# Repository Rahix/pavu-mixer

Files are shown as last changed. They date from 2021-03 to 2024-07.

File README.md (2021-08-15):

 Pavu Mixer
=================================
_Pavu Mixer_ is a hardware mixing desk for controlling
[PulseAudio](https://www.freedesktop.org/wiki/Software/PulseAudio/) streams on
a connected computer.  Think of it as a hardware version of
[`pavucontrol`](https://freedesktop.org/software/pulseaudio/pavucontrol/).

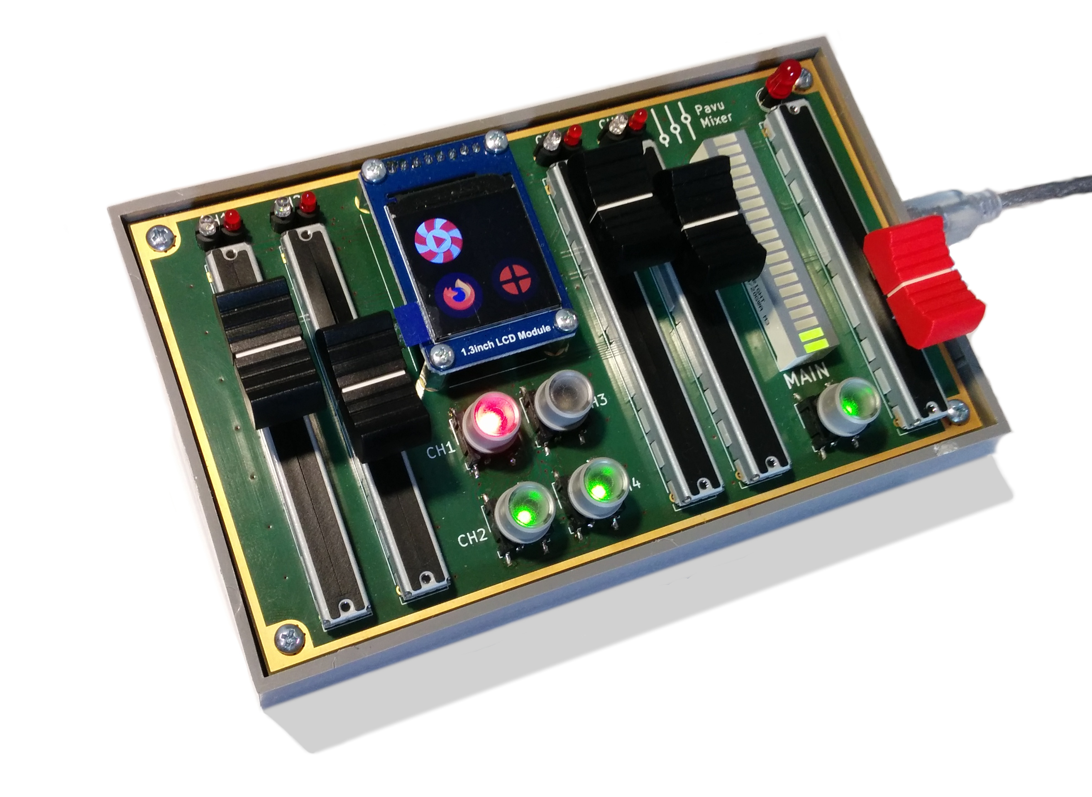
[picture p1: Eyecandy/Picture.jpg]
Pavu Mixer in Action


More pictures in [`Eyecandy/`](./Eyecandy).

### Hardware
The _Pavu Mixer_ is currently just a PCB fitted as the front plate of a
[console enclosure][enclosure].  This remedies the need for a custom front
plate.  Beneath it, an [STM32F3DISCOVERY][discovery] eval board is used as the
controller.  Connection to the computer is done over USB.

Following are the capabilities of the current hardware:

- 4 "Application Channels" + 1 "Main" Channel
- [240x240 LCD Display][display-board] (driver available in
  [`waveshare-display/`](./waveshare-display) subdirectory)
- Per channel:
  - Mono Volume Fader
  - Mute Button with green/red indicator LED
  - LED as brightness-based level indicator
  - Red LED as status indicator
- For the main channel, the level indicator is a 20 segment LED-bargraph
  instead.
- USB-B socket for connection to the computer

[enclosure]: https://www.tekoenclosures.com/en/products/family/PU/series/pult-36
[discovery]: https://www.st.com/en/evaluation-tools/stm32f3discovery.html
[display-board]: https://www.waveshare.com/wiki/1.3inch_LCD_Module

### Firmware/Software
The firmware on the [STM32F3DISCOVERY][discovery] board exposes all of the "UI"
(faders, buttons, indicators, display) to the host via a custom USB class.
Messages are serialized using [`postcard`](https://crates.io/crates/postcard).

On the host, a daemon is running which communicates to the hardware and keeps
track of PulseAudio state.  It has a configuration file for selecting which
channel controls which applications.  Streams are then attached to the mixer
channels automatically when they appear.

The firmware and host-side software are still in development - these features
are subject to change.

- New application streams are attached to channels based on a configurable
  property-matching table.  All streams connected to a channel will be forced
  to the volume reported by the fader.
- Main channel controls the currently selected default sink.
- Whenever a channel has an active stream, its reported icon will be displayed
  on the LCD.  For streams which do not properly report an icon, a second
  matching table can be used to select custom icons.

### Alternative Hardware
Right now, only the _Pavu Mixer_ hardware is supported.  As this board is not
commercially available, but a hardware mixer for PulseAudio could be
interesting for other people as well, I am open to extend the host-daemon to
support other boards as well.  For example, there are a lot of MIDI-based
digital audio mixers which would be a good candidate for support.  Please open
an issue on GitHub or contact me directly if interested.

## Project Structure
| Path | Contents |
| -- | -- |
| `Eyecandy/` | Pictures and "rendered" schematic ([`Pavu-Mixer-Schematic.pdf`](Eyecandy/Pavu-Mixer-Schematic.pdf)). |
| `Hardware/` | KiCAD project for the interface board & other hardware related files. |
| `hardware-tests/` | Test-firmware for demonstrating functionality of all parts of the hardware. |
| `common/` | Definitions shared between firmware and host-software (for [`postcard`](https://crates.io/crates/postcard) serdes). |
| `firmware/` | Firmware for the [STM32F3DISCOVERY][discovery] board. |
| `host-daemon/` | Host-side daemon for mixer communication and PulseAudio interaction. |
| `waveshare-display/` | Driver for the LCD screen (see its [README](waveshare-display/README.md) for details). |

## License
It is a difficult story... Individual parts of this project are licensed under
different terms:

- All files in the `Hardware/` directory (exception below) are licensed under
  the [CERN-OHL-W](LICENSE-HARDWARE).
- Files in `Hardware/3D` are licensed under [MIT](Hardware/3D/LICENSE-3D).
- The display driver in `waveshare-display/` is dual licensed under Apache 2/MIT
  as detailed in its own [README](waveshare-display/README.md).
- The remaining files of this project (including `common/`, `firmware/`,
  `hardware-tests/`, and `host-daemon/`) are licensed under the
  [GPL v3](LICENSE-SOFTWARE).

## Contribution
Unless you explicitly state otherwise, any contribution intentionally submitted
for inclusion in the work by you, as defined in the Apache-2.0 license, shall
be licensed as above, without any additional terms or conditions.

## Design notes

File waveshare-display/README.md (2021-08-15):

Driver for the "1.3inch LCD Module" from Waveshare
--------------------------------------------------
Driver for Waveshare's "[1.3inch LCD Module](https://www.waveshare.com/wiki/1.3inch_LCD_Module)" (240x240, RGB565):

1.3inch LCD Module

The module uses an ST7789 display controller. The driver code is adjusted for
the specific LCD panel.  I documented the initialization procedure in
[Initialization.md](Initialization.md).

The driver is intentionally barebones and only contains what is needed for
_Pavu Mixer_.  It might make sense to add proper interoperability with
[`embedded-graphics`](https://crates.io/crates/embedded-graphics) at some
point... I'll gladly accept contributions :)

## License
This display driver is licensed under either of

 * Apache License, Version 2.0 ([LICENSE-APACHE](LICENSE-APACHE) or <http://www.apache.org/licenses/LICENSE-2.0>)
 * MIT license ([LICENSE-MIT](LICENSE-MIT) or <http://opensource.org/licenses/MIT>)

at your option.

## Contribution
Unless you explicitly state otherwise, any contribution intentionally submitted
for inclusion in the work by you, as defined in the Apache-2.0 license, shall
be dual licensed as above, without any additional terms or conditions.

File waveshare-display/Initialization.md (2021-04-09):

Initialization Sequence
=======================
This is a documentation of the initialization sequence found in the official
example code.

#### `0x36` - `MADCTL`: Memory Data Access Control
Values: `0x00`

Bits:
- `7`: `MY` - Page Address Order
  - 0: Top to Bottom (**selected**)
  - 1: Bottom to Top
- `6`: `MX` - Column Address Order
  - 0: Left to Right (**selected**)
  - 1: Right to Left
- `5`: `MV` - Page/Column Order
  - 0: Normal (**selected**)
  - 1: Reverse Mode
- `4`: `ML` - Line Address Order
  - 0: LCD Refresh Top to Bottom (selected)
  - 1: LCD Refresh Bottom to Top
- `3`: `RGB` - BRGB/BGR Order
  - 0: RGB
  - 1: BGR
- `2`: `MH` - Display Data Latch Order
  - 0: LCD Refresh Left to Right
  - 1: LCD Refresh Right to Left

#### `0x3A` - `COLMOD`: Interface Pixel Format
Values: `0x05`

Bits:
- `6:4`: RGB interface color format
  - `101`: 65K of RGB interface
  - `110`: 262K of RGB interface
  - `0`: Undocumented value which is used here?
- `2:0`: Control interface color format
  - `011`: 12bit/pixel
  - `101`: 16bit/pixel (**selected**)
  - `110`: 18bit/pixel
  - `111`: 16M truncated

The "RGB interface color format" isn't set here; the datasheet suggests using
`0x55` for our purposes... Need to check what is going on here.

#### `0xB2` - `PORCTRL`: Porch Setting
Values: `0x0C 0x0C 0x00 0x33 0x33`

Probably empirically gained values for the porch settings, let's keep them.
"Separate porch control" is disabled.

#### `0xB7` - `GCTRL`: Gate Control
Values: `0x35`

Bits:
- `6:4`: VGH Setting (Voltage)
  - 0: 12.2 V
  - 1: 12.54 V
  - 2: 12.89 V
  - 3: 13.26 V
  - 4: 13.65 V
  - 5: 14.06 V
  - 6: 14.5 V
  - 7: 14.97 V
- `2:0`: VGL Setting (Voltage)
  - 0: -7.16 V
  - 1: -7.67 V
  - 2: -8.23 V
  - 3: -8.87 V
  - 4: -9.6 V
  - 5: -10.43 V
  - 6: -11.38 V
  - 7: -12.5 V

#### `0xBB` - `VCOMS`: VCOM Setting
Values: `0x19`

`0x19` -> 0.725 V

#### `0xC0` - `LCMCTRL`: LCM Control
Values: `0x2C`

Bits:
- `6`: XMY: XOR MY setting in command 36h
- `5`: XBGR: XOR RGB setting in command 36h (**selected**)
- `4`: XREV: XOR inverse setting in command 21h
- `3`: XMH: this bit can reverse source output order and only support for RGB
  interface without RAM mode (**selected**)
- `2`: XMV: XOR MV setting in command 36h (**selected**)
- `1`: XMX: XOR MX setting in command 36h
- `0`: XGS: XOR GS setting in command E4h

#### `0xC2` - `VDVVRHEN`: VDV and VRH Command Enable
Values: `0x01`

- `0`: VDV and VRH register value comes from NVM.
- `1`: VDV and VRH register value comes from command write (**selected**).

#### `0xC3` - `VRHS`: VRH Set
Values: `0x12`

`0x12` -> VAP: 4.45+( vcom+vcom offset+vdv)
`0x12` -> VAN: -4.45+( vcom+vcom offset-vdv)

#### `0xC4` - `VDVS`: VDV Set
Values: `0x20`

`0x20` -> VDV: 0 V

#### `0xC6` - `FRCTRL2`: Frame Rate Control in Normal Mode
Values: `0x0F`

Bits:
- `4:0`: RTNA
  - `0x0F` -> 60 Hz
- `7:5`: NLA - Inversion selection in normal mode
  - `0x0`: dot inversion (**selected**).
  - `0x7`: column inversion.

#### `0xD0` - `PWCTRL1`: Power Control 1
Values: `0xA4 0xA1`

`0xA4` is a fixed parameter?

Second Parameter Bits:
- `7:6`: AVDD, `2` -> 6.8 V
- `5:4`: AVCL, `2` -> -4.8 V
- `1:0`: VDS, `1` -> 2.3 V

#### `0xE0` - `PVGAMCTRL`: Positive Voltage Gamma Control
Values: `0xD0 0x04 0x0D 0x11 0x13 0x2B 0x3F 0x54 0x4C 0x18 0x0D 0x0B 0x1F 0x23`

Gamma Curve, probably calibrated for this device...

#### `0xE1` - `NVGAMCTRL`: Negative Voltage Gamma Control
Values: `0xD0 0x04 0x0C 0x11 0x13 0x2C 0x3F 0x44 0x51 0x2F 0x1F 0x1F 0x20 0x23`

Gamma Curve, probably calibrated for this device...

#### `0x21` - `INVON`: Display Inversion On
Self-explaining...

#### `0x11` - `SLPOUT`: Sleep Out
Self-explaining...

Interestingly, other drivers have added a delay after sending `SLPOUT` but here
this is not the case.  Maybe the timing allows for this here?

#### `0x29` - `DISPON`: Display On
Self-explaining...

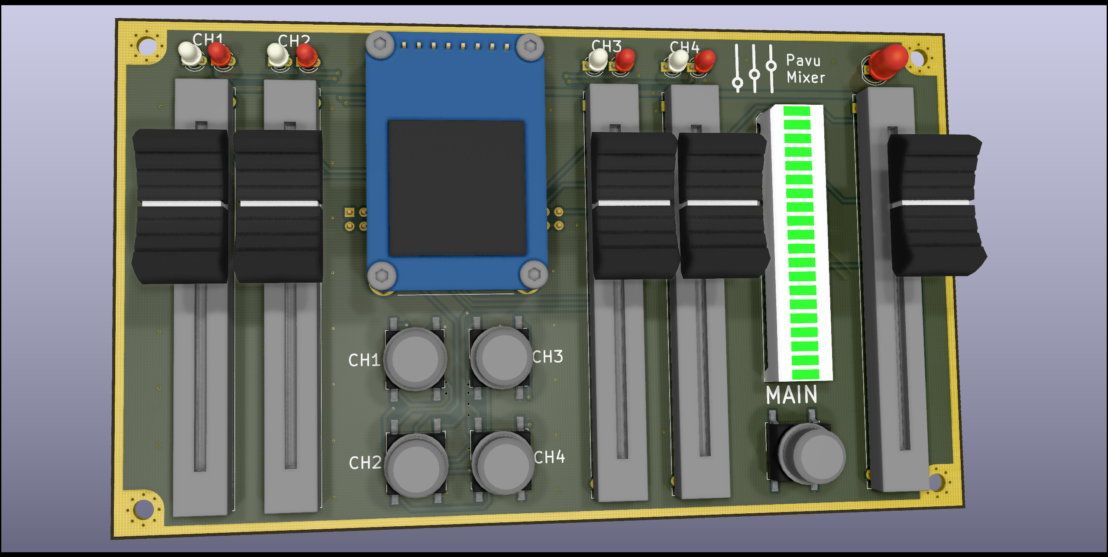
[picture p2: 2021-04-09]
Eyecandy/Render.png

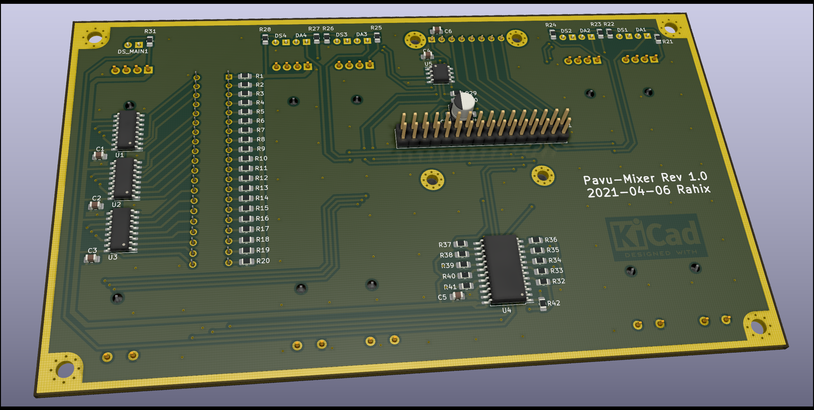
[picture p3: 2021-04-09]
Eyecandy/Render-Backside.png

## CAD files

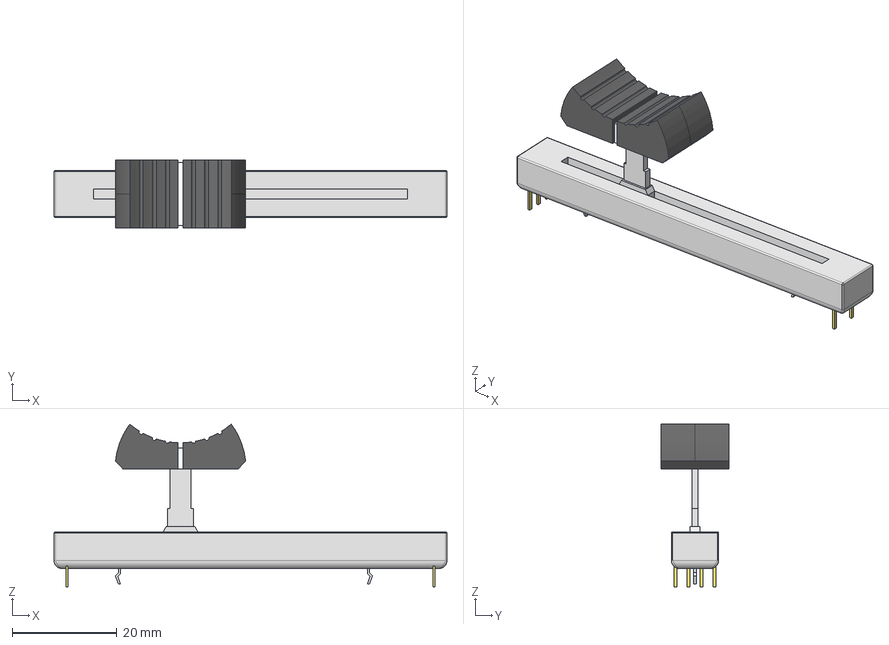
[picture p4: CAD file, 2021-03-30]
Hardware/3D/Potentiometer_Alps_RS60_Double_Slide.step
75.0 x 13.0 x 31.0 mm
5bc96c4e-9174-11eb-a0d7-8c1645fe51f1_part
5bdefa78-9174-11eb-a0d7-8c1645fe51f1_part
5bdfdfa6-9174-11eb-a0d7-8c1645fe51f1_part
5be0c0e2-9174-11eb-a0d7-8c1645fe51f1_part
5be19bac-9174-11eb-a0d7-8c1645fe51f1_part
5be2798c-9174-11eb-a0d7-8c1645fe51f1_part
5be35c8a-9174-11eb-a0d7-8c1645fe51f1_part
5be4347a-9174-11eb-a0d7-8c1645fe51f1_part
5bf3af68-9174-11eb-a0d7-8c1645fe51f1_part
5c01a550-9174-11eb-a0d7-8c1645fe51f1_part
5c2459d8-9174-11eb-a0d7-8c1645fe51f1_part
5cb7443c-9174-11eb-a0d7-8c1645fe51f1_part
5cb80944-9174-11eb-a0d7-8c1645fe51f1_part

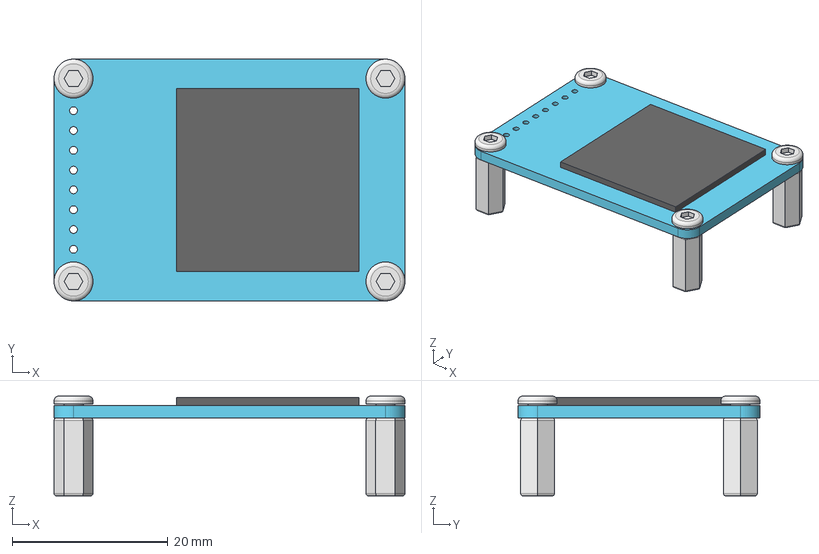
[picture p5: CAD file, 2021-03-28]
Hardware/3D/Waveshare_LCD_240X240.step
45.0 x 31.0 x 12.8 mm
428d6122-8ffd-11eb-92d6-8c1645fe51f1_part
42b24532-8ffd-11eb-92d6-8c1645fe51f1_part
42b30ff8-8ffd-11eb-92d6-8c1645fe51f1_part
42d5ac5c-8ffd-11eb-92d6-8c1645fe51f1_part
42f8973a-8ffd-11eb-92d6-8c1645fe51f1_part
431e93a4-8ffd-11eb-92d6-8c1645fe51f1_part
4340e274-8ffd-11eb-92d6-8c1645fe51f1_part

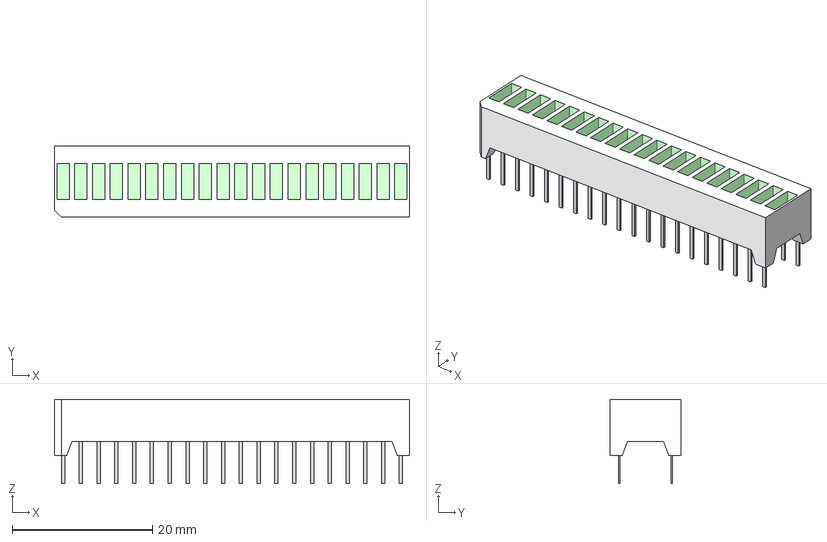
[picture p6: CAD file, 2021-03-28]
Hardware/3D/LED_BARGRAPH_20.step
50.7 x 10.2 x 12.0 mm
dbb05546-8fc9-11eb-b979-8c1645fe51f1_part
dbe73e3a-8fc9-11eb-b979-8c1645fe51f1_part
dbec1842-8fc9-11eb-b979-8c1645fe51f1_part
dbf7ca2a-8fc9-11eb-b979-8c1645fe51f1_part
dc02e928-8fc9-11eb-b979-8c1645fe51f1_part
dc0eb42e-8fc9-11eb-b979-8c1645fe51f1_part
dc1a610c-8fc9-11eb-b979-8c1645fe51f1_part
dc26386a-8fc9-11eb-b979-8c1645fe51f1_part
dc31b8c0-8fc9-11eb-b979-8c1645fe51f1_part
dc3d4f32-8fc9-11eb-b979-8c1645fe51f1_part
dc49d202-8fc9-11eb-b979-8c1645fe51f1_part
dc57cbbe-8fc9-11eb-b979-8c1645fe51f1_part
dc652a34-8fc9-11eb-b979-8c1645fe51f1_part
dc72f11e-8fc9-11eb-b979-8c1645fe51f1_part
dc7fd546-8fc9-11eb-b979-8c1645fe51f1_part
dc8c691e-8fc9-11eb-b979-8c1645fe51f1_part
dc99401c-8fc9-11eb-b979-8c1645fe51f1_part
dca56392-8fc9-11eb-b979-8c1645fe51f1_part
dcb17e70-8fc9-11eb-b979-8c1645fe51f1_part
dcbcec60-8fc9-11eb-b979-8c1645fe51f1_part
dcc72c7a-8fc9-11eb-b979-8c1645fe51f1_part
dcd17798-8fc9-11eb-b979-8c1645fe51f1_part
dcde7c7c-8fc9-11eb-b979-8c1645fe51f1_part
dcea3daa-8fc9-11eb-b979-8c1645fe51f1_part
dcf64870-8fc9-11eb-b979-8c1645fe51f1_part
dd01f800-8fc9-11eb-b979-8c1645fe51f1_part
dd0e195a-8fc9-11eb-b979-8c1645fe51f1_part
dd19154e-8fc9-11eb-b979-8c1645fe51f1_part
dd23c642-8fc9-11eb-b979-8c1645fe51f1_part
dd2e83a2-8fc9-11eb-b979-8c1645fe51f1_part
dd39aee4-8fc9-11eb-b979-8c1645fe51f1_part
dd44259a-8fc9-11eb-b979-8c1645fe51f1_part
dd4eb38e-8fc9-11eb-b979-8c1645fe51f1_part
dd593980-8fc9-11eb-b979-8c1645fe51f1_part
dd639308-8fc9-11eb-b979-8c1645fe51f1_part
dd6ed8a8-8fc9-11eb-b979-8c1645fe51f1_part
dd79103e-8fc9-11eb-b979-8c1645fe51f1_part
dd83e400-8fc9-11eb-b979-8c1645fe51f1_part
dd8ed13a-8fc9-11eb-b979-8c1645fe51f1_part
dd992676-8fc9-11eb-b979-8c1645fe51f1_part
dda3d45e-8fc9-11eb-b979-8c1645fe51f1_part
ddb12456-8fc9-11eb-b979-8c1645fe51f1_part
ddbed682-8fc9-11eb-b979-8c1645fe51f1_part

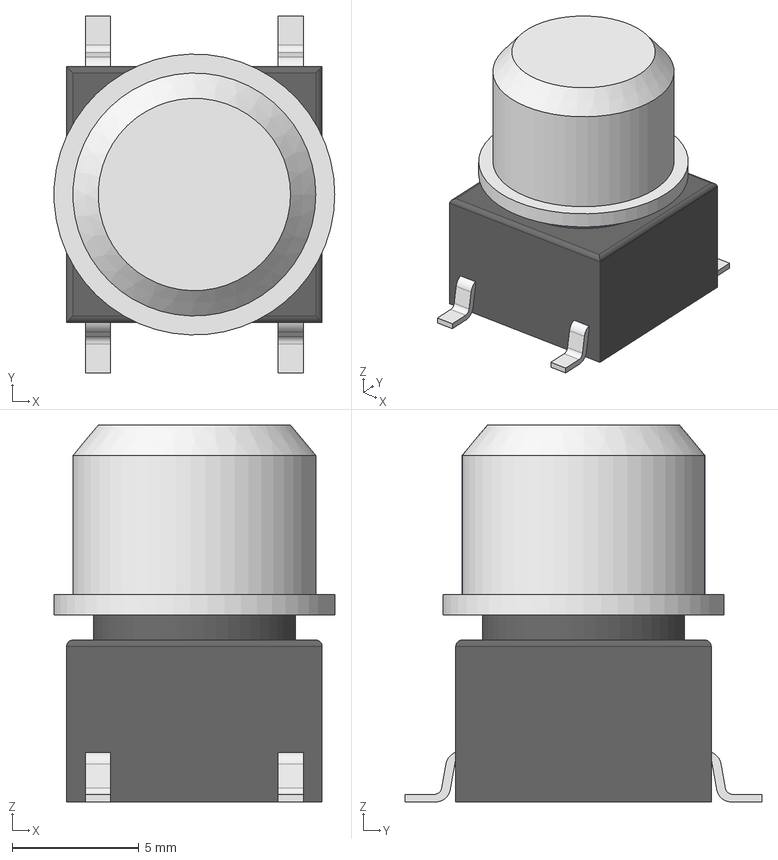
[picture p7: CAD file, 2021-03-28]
Hardware/3D/SW_MEC_5GSH9_ROUND_LED.step
11.1 x 14.1 x 14.9 mm
26c5bebe-8fd3-11eb-90f4-8c1645fe51f1_part
26d2e21a-8fd3-11eb-90f4-8c1645fe51f1_part
26e3209e-8fd3-11eb-90f4-8c1645fe51f1_part
26f2d5e8-8fd3-11eb-90f4-8c1645fe51f1_part
27024910-8fd3-11eb-90f4-8c1645fe51f1_part
2711a004-8fd3-11eb-90f4-8c1645fe51f1_part
271ab2a2-8fd3-11eb-90f4-8c1645fe51f1_part

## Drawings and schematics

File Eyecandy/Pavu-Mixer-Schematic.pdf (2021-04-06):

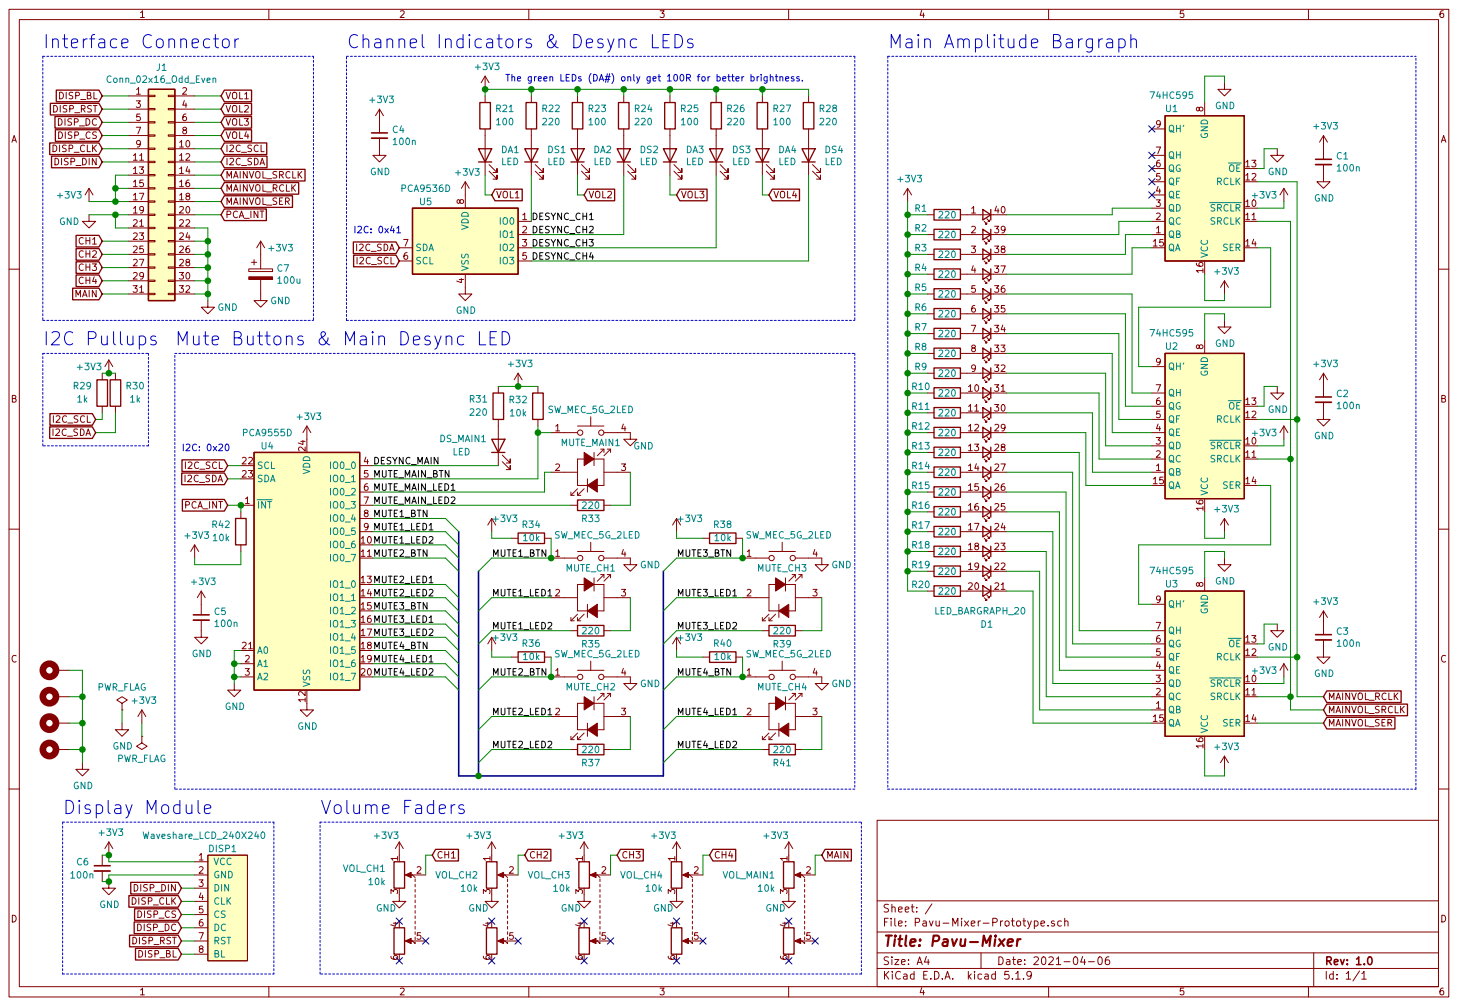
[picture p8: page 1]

Channel Indicators & Desync LEDs
220 GND

The green LEDs (DA#) only get 100R for better brightness.

Mute Buttons & Main Desync LED

File: Pavu-Mixer-Prototype.sch Sheet: /
Id: 1/1 Title: Pavu-Mixer

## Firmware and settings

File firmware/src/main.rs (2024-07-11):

#![no_std]
#![no_main]

use panic_rtt_target as _;
use rtt_target::rprintln;

use stm32f3xx_hal::{self as hal, pac, prelude::*};

use core::cell::{Cell, RefCell};

mod display;
mod faders;
mod level;
mod mute;
mod status_leds;
mod usb;

trait ResultWarn {
    fn err_warn(self, msg: &str);
}

impl<T, E> ResultWarn for Result<T, E> {
    fn err_warn(self, msg: &str) {
        match self {
            Ok(_) => (),
            Err(_) => {
                rprintln!("Error: {}", msg);
            }
        }
    }
}

fn get_device_serial(buf: &mut [u8; 16]) -> &str {
    use numtoa::NumToA;

    // SAFETY: Read-only device identifiers
    let coords = unsafe { core::ptr::read_volatile(0x1FFF_F7AC as *const u32) };
    let lotwafer = unsafe { core::ptr::read_volatile(0x1FFF_F7B0 as *const u32) };

    let serial = lotwafer.wrapping_add(coords);
    serial.numtoa_str(16, buf)
}

#[cortex_m_rt::entry]
fn main() -> ! {
    rtt_target::rtt_init_print!();

    let dp = pac::Peripherals::take().unwrap();
    let cp = cortex_m::Peripherals::take().unwrap();

    /*
     * Clocks
     * ======
     */

    let mut flash = dp.FLASH.constrain();
    let mut rcc = dp.RCC.constrain();

    let clocks = rcc
        .cfgr
        .use_hse(8u32.MHz())
        .sysclk(48u32.MHz())
        .pclk1(24u32.MHz())
        .freeze(&mut flash.acr);

    assert!(clocks.usbclk_valid());

    let mut delay = stm32f3xx_hal::delay::Delay::new(cp.SYST, clocks);

    rprintln!("Hello World!");

    let mut buf = [0; 16];
    let serial = get_device_serial(&mut buf);
    rprintln!("Device Serial: {}", serial);
    rprintln!("");

    /*
     *
     * GPIO blocks
     * ===========
     */

    let mut gpioa = dp.GPIOA.split(&mut rcc.ahb);
    let mut gpiob = dp.GPIOB.split(&mut rcc.ahb);
    let mut gpioe = dp.GPIOE.split(&mut rcc.ahb);
    let mut gpiof = dp.GPIOF.split(&mut rcc.ahb);

    /*
     * Display
     * =======
     */

    let backlight = gpiob
        .pb0
        .into_push_pull_output(&mut gpiob.moder, &mut gpiob.otyper);

    let dc = gpioa
        .pa8
        .into_push_pull_output(&mut gpioa.moder, &mut gpioa.otyper);
    let rst = gpioa
        .pa9
        .into_push_pull_output(&mut gpioa.moder, &mut gpioa.otyper);
    let cs = gpioa
        .pa4
        .into_push_pull_output(&mut gpioa.moder, &mut gpioa.otyper);

    let sck = gpioa
        .pa5
        .into_af_push_pull(&mut gpioa.moder, &mut gpioa.otyper, &mut gpioa.afrl);
    let miso = gpioa
        .pa6
        .into_af_push_pull(&mut gpioa.moder, &mut gpioa.otyper, &mut gpioa.afrl);
    let mosi = gpioa
        .pa7
        .into_af_push_pull(&mut gpioa.moder, &mut gpioa.otyper, &mut gpioa.afrl);

    let spi = stm32f3xx_hal::spi::Spi::new(
        dp.SPI1,
        (sck, miso, mosi),
        hal::spi::config::Config::default()
            .frequency(16.MHz())
            .mode(waveshare_display::SPI_MODE),
        clocks,
        &mut rcc.apb2,
    );

    let mut display = waveshare_display::WaveshareDisplay::new(spi, cs, dc, rst);
    for _ in 0..6 {
        if let Err(e) = display.initialize(&mut delay) {
            rprintln!("Failed to initialize the display: {:?}", e);
        } else {
            break;
        }
    }

    let gui = crate::display::Gui::new(display, backlight);

    rprintln!("Display initialized.");

    /*
     * Main level indicator shift register
     * ===================================
     */

    let mut main_level = level::ShiftRegLevel {
        data_pin: gpiob
            .pb15
            .into_push_pull_output(&mut gpiob.moder, &mut gpiob.otyper),
        data_clock: gpiob
            .pb13
            .into_push_pull_output(&mut gpiob.moder, &mut gpiob.otyper),
        storage_clock: gpiob
            .pb12
            .into_push_pull_output(&mut gpiob.moder, &mut gpiob.otyper),
    };

    rprintln!("ShiftRegs initialized.");

    /*
     * ADC initialization (faders)
     * ===========================
     */

    let adc_common = hal::adc::CommonAdc::new(dp.ADC1_2, &clocks, &mut rcc.ahb);
    let adc1 = hal::adc::Adc::new(
        dp.ADC1,
        hal::adc::config::Config::default(),
        &clocks,
        &adc_common,
    );

    let fader_ch1_adc = gpioa.pa0.into_analog(&mut gpioa.moder, &mut gpioa.pupdr);
    let fader_ch2_adc = gpioa.pa1.into_analog(&mut gpioa.moder, &mut gpioa.pupdr);
    let fader_ch3_adc = gpioa.pa2.into_analog(&mut gpioa.moder, &mut gpioa.pupdr);
    let fader_ch4_adc = gpioa.pa3.into_analog(&mut gpioa.moder, &mut gpioa.pupdr);
    let fader_main_adc = gpiof.pf4.into_analog(&mut gpiof.moder, &mut gpiof.pupdr);

    rprintln!("ADC initialized.");

    /*
     * PWM Channel initialization for channel level indicators
     * =======================================================
     */

    // deprecated function `stm32f3xx_hal::pwm::tim1`: needs refactoring and might violate safety
    // rules conflicting with the timer API
    #[allow(deprecated)]
    let tim1_channels = hal::pwm::tim1(dp.TIM1, 1280, 100.Hz(), &clocks);

    let pe9 = gpioe
        .pe9
        .into_af_push_pull(&mut gpioe.moder, &mut gpioe.otyper, &mut gpioe.afrh);
    let pe11 = gpioe
        .pe11
        .into_af_push_pull(&mut gpioe.moder, &mut gpioe.otyper, &mut gpioe.afrh);
    let pe13 = gpioe
        .pe13
        .into_af_push_pull(&mut gpioe.moder, &mut gpioe.otyper, &mut gpioe.afrh);
    let pe14 = gpioe
        .pe14
        .into_af_push_pull(&mut gpioe.moder, &mut gpioe.otyper, &mut gpioe.afrh);

    let ch1_level = level::PwmLevel::new(tim1_channels.0.output_to_pe9(pe9));
    let ch2_level = level::PwmLevel::new(tim1_channels.1.output_to_pe11(pe11));
    let ch3_level = level::PwmLevel::new(tim1_channels.2.output_to_pe13(pe13));
    let ch4_level = level::PwmLevel::new(tim1_channels.3.output_to_pe14(pe14));

    rprintln!("PWM initialized.");

    /*
     * I2C bus initialization
     * ======================
     */

    let mut scl =
        gpiob
            .pb6
            .into_af_open_drain(&mut gpiob.moder, &mut gpiob.otyper, &mut gpiob.afrl);
    let mut sda =
        gpiob
            .pb7
            .into_af_open_drain(&mut gpiob.moder, &mut gpiob.otyper, &mut gpiob.afrl);
    scl.internal_pull_up(&mut gpiob.pupdr, true);
    sda.internal_pull_up(&mut gpiob.pupdr, true);

    let pca_int = gpioa
        .pa10
        .into_floating_input(&mut gpioa.moder, &mut gpioa.pupdr);

    let i2c = shared_bus::BusManagerSimple::new(hal::i2c::I2c::new(
        dp.I2C1,
        (scl, sda),
        100_000.Hz(),
        clocks,
        &mut rcc.apb1,
    ));

    rprintln!("I2C bus initialized.");

    /*
     * I2C port-expanders for desync LEDs and mute-buttons
     * ===================================================
     */

    let mut pca9536 = port_expander::Pca9536::new(i2c.acquire_i2c());
    let pca9536_pins = pca9536.split();
    let mut pca9555 = port_expander::Pca9555::new(i2c.acquire_i2c(), false, false, false);
    let pca9555_pins = pca9555.split();

    let mut status_leds_main = status_leds::ChannelStatusLeds {
        sync_led: pca9555_pins.io0_0.into_output_high().unwrap(),
        button_led1: pca9555_pins.io0_2.into_output_high().unwrap(),
        button_led2: pca9555_pins.io0_3.into_output_high().unwrap(),
    };
    let mut status_leds_ch1 = status_leds::ChannelStatusLeds {
        sync_led: pca9536_pins.io0.into_output_high().unwrap(),
        button_led1: pca9555_pins.io0_5.into_output_high().unwrap(),
        button_led2: pca9555_pins.io0_6.into_output_high().unwrap(),
    };
    let mut status_leds_ch2 = status_leds::ChannelStatusLeds {
        sync_led: pca9536_pins.io1.into_output_high().unwrap(),
        button_led1: pca9555_pins.io1_0.into_output_high().unwrap(),
        button_led2: pca9555_pins.io1_1.into_output_high().unwrap(),
    };
    let mut status_leds_ch3 = status_leds::ChannelStatusLeds {
        sync_led: pca9536_pins.io2.into_output_high().unwrap(),
        button_led1: pca9555_pins.io1_3.into_output_high().unwrap(),
        button_led2: pca9555_pins.io1_4.into_output_high().unwrap(),
    };
    let mut status_leds_ch4 = status_leds::ChannelStatusLeds {
        sync_led: pca9536_pins.io3.into_output_high().unwrap(),
        button_led1: pca9555_pins.io1_6.into_output_high().unwrap(),
        button_led2: pca9555_pins.io1_7.into_output_high().unwrap(),
    };

    status_leds_main
        .set_sync(false)
        .err_warn("Failed setting LEDs");
    status_leds_ch1
        .set_sync(false)
        .err_warn("Failed setting LEDs");
    status_leds_ch2
        .set_sync(false)
        .err_warn("Failed setting LEDs");
    status_leds_ch3
        .set_sync(false)
        .err_warn("Failed setting LEDs");
    status_leds_ch4
        .set_sync(false)
        .err_warn("Failed setting LEDs");

    let mute_main = pca9555_pins.io0_1;
    let mute_ch1 = pca9555_pins.io0_4;
    let mute_ch2 = pca9555_pins.io0_7;
    let mute_ch3 = pca9555_pins.io1_2;
    let mute_ch4 = pca9555_pins.io1_5;

    // Read inputs once to clear interrupt
    port_expander::read_multiple([&mute_main, &mute_ch1, &mute_ch2, &mute_ch3, &mute_ch4])
        .err_warn("Failed reading buttons");

    // Set all outputs appropriately
    status_leds_main
        .set_button_led(status_leds::Led::Green)
        .err_warn("Failed setting LEDs");
    status_leds_ch1
        .set_button_led(status_leds::Led::Off)
        .err_warn("Failed setting LEDs");
    status_leds_ch2
        .set_button_led(status_leds::Led::Off)
        .err_warn("Failed setting LEDs");
    status_leds_ch3
        .set_button_led(status_leds::Led::Off)
        .err_warn("Failed setting LEDs");
    status_leds_ch4
        .set_button_led(status_leds::Led::Off)
        .err_warn("Failed setting LEDs");

    if pca_int.is_low().unwrap() {
        rprintln!("PCA interrupt is asserted when it should not be!");
    }

    rprintln!("PCA9536 & PCA9555 initialized.");

    /*
     * USB FS
     * ======
     */

    /*
     * F3 Discovery board has a pull-up resistor on the D+ line.
     * Pull the D+ pin down to send a RESET condition to the USB bus.
     * This forced reset is needed only for development, without it host
     * will not reset your device when you upload new firmware.
     */
    let mut usb_dp = gpioa
        .pa12
        .into_push_pull_output(&mut gpioa.moder, &mut gpioa.otyper);
    usb_dp.set_low().ok();
    cortex_m::asm::delay(clocks.sysclk().0 / 100);

    let usb = hal::usb::Peripheral {
        usb: dp.USB,
        pin_dm: gpioa.pa11.into_af_push_pull(
            &mut gpioa.moder,
            &mut gpioa.otyper,
            &mut gpioa.afrh,
        ),
        pin_dp: usb_dp.into_af_push_pull(&mut gpioa.moder, &mut gpioa.otyper, &mut gpioa.afrh),
    };
    let usb_bus = hal::usb::UsbBus::new(usb);

    let usb_class = RefCell::new(usb::PavuMixerClass::new(&usb_bus));

    let mut usb_dev = usb_device::prelude::UsbDeviceBuilder::new(
        &usb_bus,
        // random VID:PID.....
        usb_device::prelude::UsbVidPid(0xde5f, 0x3d20),
    )
    // General Information
    .manufacturer("Rahix")
    .product("Pavu Mixer")
    .device_release(0x0010)
    .serial_number(serial)
    // Power
    .self_powered(false)
    .max_power(400)
    // Device Class
    .device_class(0xff)
    .build();

    rprintln!("USB device initialized.");

    let pending_volume_updates =
        RefCell::new(heapless::LinearMap::<common::Channel, f32, 5>::new());
    let pending_presses = RefCell::new(heapless::LinearMap::<common::Channel, (), 5>::new());
    let pending_forced_update = Cell::new(false);

    rprintln!("Ready.");
    rprintln!("");

    // Update main level to full to indicate that we are ready.
    main_level.update_level(1.0);

    let usb_recv_task = usb::usb_recv_task(
        &mut usb_dev,
        &usb_class,
        main_level,
        status_leds_main,
        ch1_level,
        status_leds_ch1,
        ch2_level,
        status_leds_ch2,
        ch3_level,
        status_leds_ch3,
        ch4_level,
        status_leds_ch4,
        gui,
        &pending_forced_update,
    );
    futures_util::pin_mut!(usb_recv_task);

    let usb_send_task = usb::usb_send_task(&usb_class, &pending_volume_updates, &pending_presses);
    futures_util::pin_mut!(usb_send_task);

    let mute_buttons_task = mute::mute_buttons_task(
        pca_int,
        mute_main,
        mute_ch1,
        mute_ch2,
        mute_ch3,
        mute_ch4,
        &pending_presses,
    );
    futures_util::pin_mut!(mute_buttons_task);

    let faders_task = faders::faders_task(
        adc1,
        fader_main_adc,
        fader_ch1_adc,
        fader_ch2_adc,
        fader_ch3_adc,
        fader_ch4_adc,
        &pending_volume_updates,
        &pending_forced_update,
    );
    futures_util::pin_mut!(faders_task);

    let all_tasks = async {
        // join!() all tasks to poll them one after the other indefinitely.
        futures_util::join!(usb_recv_task, usb_send_task, mute_buttons_task, faders_task);
    };
    futures_util::pin_mut!(all_tasks);

    let c = cassette::Cassette::new(all_tasks);
    c.block_on();
    unreachable!();
}

#[cortex_m_rt::exception]
unsafe fn HardFault(ef: &cortex_m_rt::ExceptionFrame) -> ! {
    panic!("Hard Fault: {:#?}", ef);
}

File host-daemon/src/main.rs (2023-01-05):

use anyhow::Context;

mod channel;
mod config;
mod connection;
mod icon;
mod pa;

fn main() -> anyhow::Result<()> {
    env_logger::builder()
        .filter(
            Some("pavu_mixer_host"),
            if cfg!(debug_assertions) {
                log::LevelFilter::Debug
            } else {
                log::LevelFilter::Info
            },
        )
        .init();

    let config: config::Config =
        confy::load("pavu-mixer", Some("pavu-mixer")).context("failed loading configuration")?;

    let mut pavu_mixer =
        connection::PavuMixer::connect(&config.connection).context("failed connecting to mixer")?;

    loop {
        let error = match run(&config, pavu_mixer) {
            Ok(()) => return Ok(()),
            Err(e) => e,
        };

        if error
            .downcast_ref::<connection::DeviceDisconnectedError>()
            .is_some()
        {
            log::info!("PavuMixer disconnected, retrying in 2 seconds...");
            std::thread::sleep(std::time::Duration::from_secs(2));
            pavu_mixer = connection::PavuMixer::connect(&config.connection)
                .context("failed connecting to mixer")?;
        } else {
            return Err(error);
        }
    }
}

fn run(config: &config::Config, mut pavu_mixer: connection::PavuMixer) -> anyhow::Result<()> {
    gtk::init()?;

    let mut main = channel::Channel::new(None);
    let mut channels = [
        channel::Channel::new(Some(config.channel_1.property_matches.clone())),
        channel::Channel::new(Some(config.channel_2.property_matches.clone())),
        channel::Channel::new(Some(config.channel_3.property_matches.clone())),
        channel::Channel::new(Some(config.channel_4.property_matches.clone())),
    ];

    let mut pa = pa::PulseInterface::init().context("failed initializing pulseaudio client")?;

    let events = pa.take_event_receiver().expect("events channel missing");

    // When we start up, there might still be some messages waiting for us - drop them because we
    // will request up-to-date ones in the next step.
    while let Some(message) = pavu_mixer.try_recv().context("failed reading from mixer")? {
        log::debug!("Dropping stale message from device: {:?}", message);
    }

    // Put all channels into known state.
    for ch in [
        common::Channel::Main,
        common::Channel::Ch1,
        common::Channel::Ch2,
        common::Channel::Ch3,
        common::Channel::Ch4,
    ] {
        pavu_mixer
            .send(common::HostMessage::UpdateChannelState(
                ch,
                common::ChannelState::Inactive,
            ))
            .context("failed sending message to device")?;
        pavu_mixer
            .send(common::HostMessage::UpdatePeak(ch, 0.0))
            .context("failed sending message to device")?;
    }

    // Force an update during daemon startup so we'll have up-to-date values for all channels.
    pavu_mixer.send(common::HostMessage::ForceUpdate)?;

    let mut active_sink = None;

    loop {
        // Handle all pending events from PulseAudio.
        for event in events.try_iter() {
            match event {
                pa::Event::NewDefaultSink(stream) => {
                    main.detach_all();
                    let (stream, index, state) = main.attach_stream(&mut pa, stream);
                    stream.set_connected_channel(common::Channel::Main, index);
                    stream.connect()?;
                    active_sink = stream.sink_name();
                    pavu_mixer.send(common::HostMessage::UpdateChannelState(
                        common::Channel::Main,
                        state,
                    ))?;
                }
                pa::Event::NewPeakData(ch, index) => {
                    let mut peak = match ch {
                        common::Channel::Main => main.update_peak(index)?,
                        ch => channels[ch.to_index()].update_peak(index)?,
                    };
                    for multi in config.sink_peak_multiplier.iter() {
                        if active_sink.as_deref() == Some(&multi.sink_name) {
                            peak *= multi.multiplier;
                            break;
                        }
                    }
                    pavu_mixer.send(common::HostMessage::UpdatePeak(ch, peak))?;
                }
                pa::Event::SinkInputAdded(info) => {
                    // check whether this sink-input should be connected to one of our channels -
                    // if yes, request a stream for it.
                    for (index, channel) in channels.iter().enumerate() {
                        if channel.match_sink_input(&info) {
                            let ch = common::Channel::from_index(index);
                            log::debug!(
                                "Attached stream \"{}/{}\" to channel {:?}",
                                info.name.as_deref().unwrap_or(""),
                                info.application.as_deref().unwrap_or(""),
                                ch
                            );
                            pa.request_sink_input_stream(info, ch);
                            break;
                        }
                    }
                }
                pa::Event::NewSinkInput(ch, stream) => {
                    let channel = &mut channels[ch.to_index()];
                    // only add this channel if there isn't one already
                    if channel
                        .index_for_sink_input(stream.sink_input_index().unwrap())
                        .is_none()
                    {
                        let (stream, index, state) = channel.attach_stream(&mut pa, stream);
                        stream.set_connected_channel(ch, index);
                        stream.connect()?;
                        pavu_mixer.send(common::HostMessage::UpdateChannelState(ch, state))?;
                        if let Some(icon_name) = stream.get_icon_name(&config.icon_mappings) {
                            log::debug!("Icon {:?} for Channel {:?}", icon_name, ch);
                            if let Some(icon_data) = icon::get_icon_data(&icon_name) {
                                pavu_mixer.send(common::HostMessage::SetIcon(ch))?;
                                pavu_mixer.send_bulk(&icon_data)?;
                            }
                        }
                    }
                }
                pa::Event::SinkInputChanged(info) => {
                    for (cidx, channel) in channels.iter().enumerate() {
                        if channel.match_sink_input(&info) {
                            // check if this channel already owns the sink-input
                            if channel.index_for_sink_input(info.index).is_some() {
                                break;
                            }
                            let ch = common::Channel::from_index(cidx);
                            log::debug!(
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

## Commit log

2021-03-28 Initial
    Add Footprints and 3D Models for some components
    [LED_BARGRAPH_20.step, Potentiometer_Alps_RS60_Double_Slide.step, SW_MEC_5GSH9_ROUND_LED.step]
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2021-03-28 Add KiCad project
    [Pavu-Mixer-Prototype.kicad_pcb, Pavu-Mixer-Prototype.sch]
2021-03-28 Add rough project sketch
    [Pavu-Mixer-Prototype.kicad_pcb, Pavu-Mixer-Prototype.sch]
2021-03-28 Mounting Holes
    [Pavu-Mixer-Prototype.kicad_pcb, Pavu-Mixer-Prototype.sch]
2021-03-28 GND Net for mounting holes
    [Pavu-Mixer-Prototype.kicad_pcb, Pavu-Mixer-Prototype.sch]
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2021-03-28 Add channel LEDs
    [Pavu-Mixer-Prototype.kicad_pcb, Pavu-Mixer-Prototype.sch]
2021-03-28 Fix master mute position
    [Pavu-Mixer-Prototype.kicad_pcb]
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2021-03-28 Add display to PCB sketch
    [Pavu-Mixer-Prototype.kicad_pcb, Pavu-Mixer-Prototype.sch]
2021-03-28 Update display footprint and add 3D model
    [Waveshare_LCD_240X240.step]
2021-03-28 Update display footpring in the PCB
    [Pavu-Mixer-Prototype.kicad_pcb]
2021-03-28 Add 2 more spacers to display
    [Pavu-Mixer-Prototype.kicad_pcb, Waveshare_LCD_240X240.step]
2021-03-28 Add GND zone around the board
    [Pavu-Mixer-Prototype.kicad_pcb]
2021-03-28 Ring around the board on both sides
    [Pavu-Mixer-Prototype.kicad_pcb]
2021-03-28 Adjust fader positioning
    [Pavu-Mixer-Prototype.kicad_pcb]
2021-03-28 Fix F.Fab reference labels
    [Pavu-Mixer-Prototype.kicad_pcb]
2021-03-28 Start working on the electrical details
    [Pavu-Mixer-Prototype.kicad_pcb, Pavu-Mixer-Prototype.sch]
2021-03-28 More schematic design
    [Pavu-Mixer-Prototype.sch]
2021-03-28 Everyone has a connection now
    [Pavu-Mixer-Prototype.kicad_pcb, Pavu-Mixer-Prototype.sch]
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2021-03-28 Schematic is complete
    [Pavu-Mixer-Prototype.sch]
2021-03-28 Add missing footprints
    [Pavu-Mixer-Prototype.sch]
2021-03-28 Add connector footprint
    [Pavu-Mixer-Prototype.sch]
2021-03-29 Rough component placement
    [Pavu-Mixer-Prototype.kicad_pcb]
2021-03-29 Update connector pinout
    [Pavu-Mixer-Prototype.kicad_pcb, Pavu-Mixer-Prototype.sch]
2021-03-29 Update silkscreen placements
    [Pavu-Mixer-Prototype.kicad_pcb]
2021-03-29 Add power flags to make ERC happy
    [Pavu-Mixer-Prototype.sch]
2021-03-29 Import AISLER design rules
    [Pavu-Mixer-Prototype.kicad_pcb]
2021-03-29 Center the board on the sheet
    [Pavu-Mixer-Prototype.kicad_pcb]
2021-03-29 Fully routed layout
    [Pavu-Mixer-Prototype.kicad_pcb, Pavu-Mixer-Prototype.sch]
2021-03-29 Minor routing improvements
    [Pavu-Mixer-Prototype.kicad_pcb]
2021-03-29 More minor improvements
    [Pavu-Mixer-Prototype.kicad_pcb]
2021-03-29 Fix shift register OE being pulled high instead of low
    [Pavu-Mixer-Prototype.kicad_pcb, Pavu-Mixer-Prototype.sch]
2021-03-29 Fix shift register GND connections
    [Pavu-Mixer-Prototype.kicad_pcb]
2021-03-29 Cleanup some tracks
    [Pavu-Mixer-Prototype.kicad_pcb]
2021-03-29 Document I2C bus addresses
    [Pavu-Mixer-Prototype.sch]
2021-03-29 Add pull-up for PCA_INT signal
    [Pavu-Mixer-Prototype.kicad_pcb, Pavu-Mixer-Prototype.sch]
2021-03-29 LED Series resistors 100 ohm instead of 47
    [Pavu-Mixer-Prototype.kicad_pcb, Pavu-Mixer-Prototype.sch]
2021-03-29 Tidy up the schematic a bit
    [Pavu-Mixer-Prototype.sch]
2021-03-29 Add I2C Pull-Up Resistors
    [Pavu-Mixer-Prototype.kicad_pcb, Pavu-Mixer-Prototype.sch]
2021-03-29 Add mute button pull-ups
    [Pavu-Mixer-Prototype.kicad_pcb, Pavu-Mixer-Prototype.sch]
2021-03-29 Update fader position
    [Potentiometer_Alps_RS60_Double_Slide.step]
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2021-03-30 Move resistors to the backside and reroute everything
    [Pavu-Mixer-Prototype.kicad_pcb]
2021-03-30 Cleanup PCB Layout a bit
    [Pavu-Mixer-Prototype.kicad_pcb]
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2021-03-30 Fix wrong pin coords in Fader 3D Model
    [Potentiometer_Alps_RS60_Double_Slide.step]
2021-04-01 Add decoupling capacitors
    [Pavu-Mixer-Prototype.sch]
2021-04-01 Renumber resistors
    [Pavu-Mixer-Prototype.sch]
2021-04-03 hardware: Layout & route the decoupling capacitors
    [Pavu-Mixer-Prototype.kicad_pcb]
2021-04-03 hardware: Use 10k pull-ups for the buttons
    [Pavu-Mixer-Prototype.sch]
2021-04-03 hardware: Bigger LED resistors
    [Pavu-Mixer-Prototype.sch]
2021-04-03 hardware: More capacitors
    [Pavu-Mixer-Prototype.sch]
2021-04-03 hardware: Route display decoupling capacitor
    [Pavu-Mixer-Prototype.kicad_pcb]
2021-04-04 hardware: Update PCB layout
    [Pavu-Mixer-Prototype.kicad_pcb]
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2021-04-05 hardware: Sync PCB from schematic
    [Pavu-Mixer-Prototype.kicad_pcb]
2021-04-06 hardware: Improve label locations
    [Pavu-Mixer-Prototype.kicad_pcb]
2021-04-06 hardware: Update KiCad logo placement
    [Pavu-Mixer-Prototype.kicad_pcb]
2021-04-06 hardware: Update nets from schematic
    [Pavu-Mixer-Prototype.kicad_pcb]
2021-04-06 hardware: Update label placement once more
    [Pavu-Mixer-Prototype.kicad_pcb]
2021-04-06 hardware: Update PCB layout once more
    [Pavu-Mixer-Prototype.kicad_pcb]
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2021-04-06 hardware: Update date
    [Pavu-Mixer-Prototype.kicad_pcb, Pavu-Mixer-Prototype.sch]
2021-04-06 hardware: Add more artwork
    [Pavu-Mixer-Prototype.kicad_pcb]
2021-04-06 hardware: Cleanup PCB layout
    [Pavu-Mixer-Prototype.kicad_pcb]
2021-04-06 hardware: Final copper pour cleanup
    [Pavu-Mixer-Prototype.kicad_pcb]
2021-04-06 hardware: Tweak some via positions slightly
    [Pavu-Mixer-Prototype.kicad_pcb]
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2021-04-17 firmware: Hack up a basic MVP
    Read the current main volume level from a custom USB class.
2021-04-17 host-daemon: Fix laggy peak display
    We actually have to call peek in a loop for every fragment we might be
    getting.
    [main.rs]
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2021-04-17 host-daemon: Improvements
    Better error contexts + implement sudo hack
    [main.rs]
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2021-04-18 host-daemon: Don't error on missing peak data
    [main.rs]
2021-04-18 host-daemon: Reconfigure on stream read error
    [main.rs]
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2021-04-23 firmware: Correctly initialize main channel LED
    [main.rs]
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2021-04-26 firmware: Switch to git version of stm32f3xx-hal
    The released version is quite dated and contains bugs like
    a multi-second delay during ADC initialization. Switch to the latest
    git version instead to mitigate these issues.
    [main.rs]
2021-04-26 firmware: Remove outdated comment about ADC startup delay
    This was fixed upstream [1] and with the switch to the git version of
    stm32f3xx-hal, we no longer face this issue.
    [1]: https://github.com/stm32-rs/stm32f3xx-hal/pull/217
    [main.rs]
2021-04-26 host-daemon: Apply "temporary" fix to SEGFAULT on exit
    For some reason, dropping the libpulse binding data structures leads to
    a segfault. I'm unsure where exactly this comes from but it might have
    to do with the "relaxed" handling of callback liveness validation done
    in the libpulse rust binding (= a callback gets called which does not
    exist anymore).
    [main.rs]
2021-04-27 firmware: Drop "loading bar"
    It's too fast for this to make sense now that the ADC delay bug is
    fixed.
    [main.rs]
2021-05-17 firmware: Start conversion to async
    Make the firmware use async Rust on the basis of the cassette [1]
    executor. For now, only USB and faders are converted but the rest is to
    follow.
    [1]: https://github.com/jamesmunns/cassette
    [main.rs, usb.rs]
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2021-07-16 host-daemon: Start reworking the PulseAudio interface
    The interface needs to be much more flexible and robust than it
    currently is. Namely, we need to support multiple streams on the same
    channel.
    [main.rs]
2021-07-17 host-daemon: Improve peak handling
    When get_recent_peak() returns an error, set the stream's peak to 0 so
    it won't influence the calculated channel peak anymore.
    [main.rs]
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2021-08-04 host-daemon: Drop streams which are no longer active
    [main.rs]
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2021-08-04 firmware: Legwork for icon messages
    Get everything in place to support application icons. This initial
    support might still be brittle because it will not work properly when
    bulk-data is sent without a `SetIcon()` message preceeding it.
    [main.rs, usb.rs]
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2021-08-04 host-daemon: Put channels into known state on startup
    To make sure no previous information "leaks" into the system after
    restarting the daemon, begin by sending channel state updates for all
    channels to reset their state to a good default.
    [main.rs]
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2021-08-09 host-daemon: connection: Treat disconnect errors differently
    Return a different error type when the device disconnected. This can be
    used further up to handle disconnects gracefully.
2021-08-14 host-daemon: Do not report error on disconnect
    Instead of reporting an error, terminate normally.
    [main.rs]
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2021-08-14 firmware: Fix main level always being at least 1
    The lowest bar of the main level was always on - off by one errors still
    rule the world to this day.
    Fixing this is also the last remaining step towards fully putting the
    interface to sleep on bus suspend.
    [level.rs]
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2021-08-14 firmware: Fix TOCTOU race condition
    Fix a race condition where a new fader value would not actually be sent
    to the host if the update occurred while in the process of sending the
    previous value.
    [usb.rs]
2021-08-14 firmware: Always sent the most recent volume value
    Due to the implicit inner loop from send_device_message_async(), we
    sometimes send a value older than what's available. Fix this by not
    relying in send_device_message_async() but instead fetching the latest
    value for each send attempt.
    [usb.rs]
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2022-02-07 host-daemon: Wait before attempting to reconnect
    This hopefully yields a higher chance of the reconnect actually
    succeeding. When reconnecting too fast, sometimes a "resource busy"
    error was observed.
    [main.rs]
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2022-02-08 host-daemon: Ensure no superfluous streams are connected
    Due to now listening on sink-input change events, we sometimes get many
    streams connecting to the same sink-input at the same time (due to many
    change events in rapid succession).
    We can prevent this quite well by delaying the actual "connection" until
    after the point where we checked whether this stream will actually be
    needed.
    [main.rs]
2023-01-05 firmware: Fix a compiler warning
    [faders.rs]
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2024-07-08 firmware: Don't panic on non-critical errors
    Instead log a warning to a connected debugger if possible.
    [main.rs, mute.rs, usb.rs]
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2024-07-08 firmware: Fix compiler warnings
    [main.rs]
2024-07-08 waveshare-display: Reduce reset time
    It seems the reset time does not need to be anywhere near this long so
    let's reduce it to speed up the boot process.
    [lib.rs]
2024-07-09 firmware: Fix compiler warning
    [usb.rs]
2024-07-11 firmware: Fix LED glitch during startup
    Prevent a short glitch of the LEDs during startup which was caused by
    not setting the LEDs to the correct state before configuring the I/O
    pins as outputs.
    [main.rs]
2026-01-10 host-daemon: Fail gracefully when USB device disappears
    Don't return an error exit-code when the USB device vanishes entirely.
    We can use this to instruct systemd to restart the service on abnormal
    failures but not when the device is gone.
2026-01-10 host-daemon: Fix icon mappings not performing regex match
    This led to icons often not being assigned even though the mappings
    should have matched.
    Fixes: 832df5ca6cad ("host-daemon: Allow matching regex patterns")
2026-01-10 host-daemon: Also fail gracefully on first start
    Fixes: b7175764fad2 ("host-daemon: Fail gracefully when USB device disappears")
